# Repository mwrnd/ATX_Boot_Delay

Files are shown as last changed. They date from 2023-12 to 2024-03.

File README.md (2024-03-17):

# ATX Boot Delay

Delaying a motherboard's BIOS/UEFI boot is a simple trick that solves issues related to the [PCIe Specification's 100ms time limit](https://pcisig.com/specifications/ecr_ecn_process?speclib=100+ms). This can be done by toggling a computer's POWER button, then pressing and holding the RESET button for a second before releasing it. Or, connect a capacitor across the reset pins of an ATX motherboard's [Front Panel Header](https://www.intel.com/content/www/us/en/support/articles/000007309/intel-nuc.html).

This board is a simple 9-Pin Front Panel Header in-line replacement for ATX motherboards that allows choosing capacitor(s) to connect accross the RESET pins to delay boot.

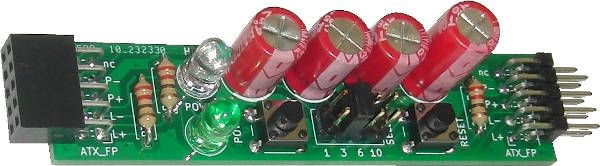
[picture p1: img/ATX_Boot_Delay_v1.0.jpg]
ATX Boot Delay Board


To use the RESET button on the board, hold it long enough to overcome the capacitor discharge delay which can be a couple of seconds.

## Usage Example

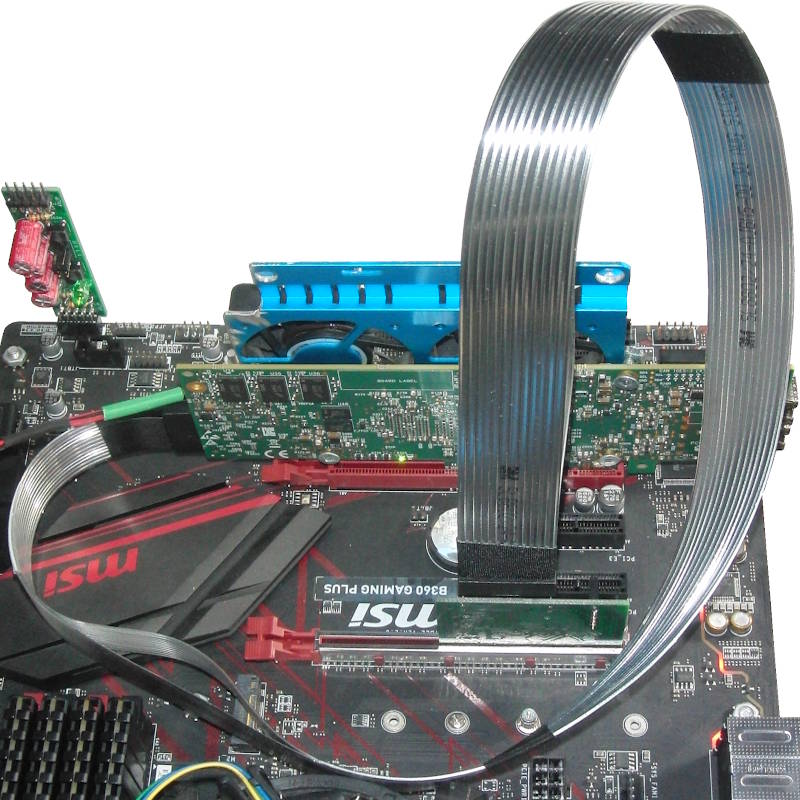
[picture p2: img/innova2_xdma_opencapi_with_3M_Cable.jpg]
ATX Boot Delay Board in a System


Close-up:

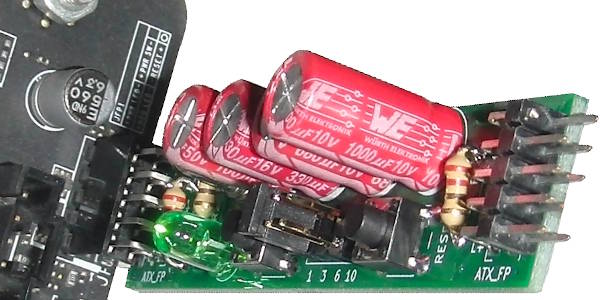
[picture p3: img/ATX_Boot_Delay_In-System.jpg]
ATX Boot Delay Board in a System Closeup


## PCB Layout

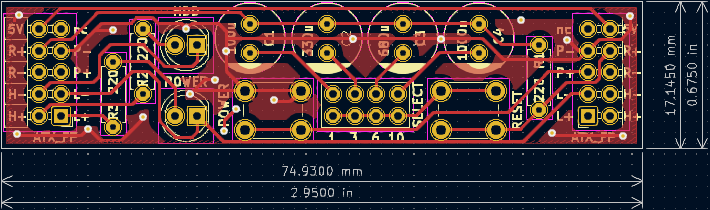
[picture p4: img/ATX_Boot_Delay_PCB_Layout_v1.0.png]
ATX Boot Delay Board PCB Layout


## Schematic

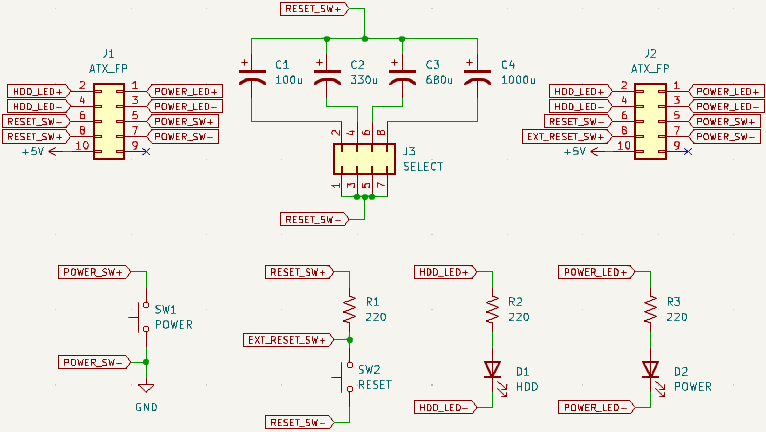
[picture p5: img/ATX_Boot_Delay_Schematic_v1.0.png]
ATX Boot Delay Board Schematic


## Bill Of Materials

| Designator(s) | Part Number | Quantity | Value | Footprint | Availability |
| --- | --- | --- | --- | --- | --- |
| C1 | 860010674014 | 1 | 100uF | C_Radial_D8.0mm_H11.5mm_P3.50mm | [DigiKey](https://www.digikey.com/en/products/detail/w%C3%BCrth-elektronik/860010674014/5726913) |
| C2 | 860010374011 | 1 | 330uF | C_Radial_D8.0mm_H11.5mm_P3.50mm | [DigiKey](https://www.digikey.com/en/products/detail/w%C3%BCrth-elektronik/860010374011/5726852) |
| C3 | 860020274013 | 1 | 680uF | C_Radial_D8.0mm_H11.5mm_P3.50mm | [DigiKey](https://www.digikey.com/en/products/detail/w%C3%BCrth-elektronik/860020274013/5727150) |
| C4 | 860010274015 | 1 | 1000uF  | C_Radial_D8.0mm_H11.5mm_P3.50mm | [DigiKey](https://www.digikey.com/en/products/detail/w%C3%BCrth-elektronik/860010274015/5726956) |
| SW1, SW2 | TS02-66-60-BK-100-LCR-D | 2 | N/A | SW_PUSH_6mm | [DigiKey](https://www.digikey.com/en/products/detail/cui-devices/TS02-66-60-BK-100-LCR-D/15634327) |
| J1 | PREC005DBAN-M71RC | 1 | N/A | PinSocket_2x05_P2.54mm_Horizontal | [DigiKey](https://www.digikey.com/en/products/detail/sullins-connector-solutions/PREC005DBAN-M71RC/2775649) |
| J2 | PPTC052LJBN-RC | 1 | N/A | PinHeader_2x05_P2.54mm_Horizontal | [DigiKey](https://www.digikey.com/en/products/detail/sullins-connector-solutions/PPTC052LJBN-RC/775977) |
| J3 | 9-146257-0-04 | 1 | N/A | PinHeader_2x04_P2.54mm_Vertical | [DigiKey](https://www.digikey.com/en/products/detail/te-connectivity-amp-connectors/9-146257-0-04/1165365)  |
| D1 | C503B-RAN-CZ0C0AA2 | 1 | RED | LED_D5.0mm | [DigiKey](https://www.digikey.com/en/products/detail/creeled-inc/C503B-RAN-CZ0C0AA2/6561762) |
| D2 | LTL-4234 | 1 | GREEN | LED_D5.0mm | [DigiKey](https://www.digikey.com/en/products/detail/liteon/LTL-4234/200373) |
| R1, R2, R3 | CF14JT220R | 1 | 220-Ohm | R_Axial_DIN0207_L6.3mm_D2.5mm | [DigiKey](https://www.digikey.com/en/products/detail/stackpole-electronics-inc/CF14JT220R/1741346) |
| Jumpers | QPC02SXGN-RC | 4 | N/A | N/A | [DigiKey](https://www.digikey.com/en/products/detail/sullins-connector-solutions/QPC02SXGN-RC/2618262) |

## Theory of Operation

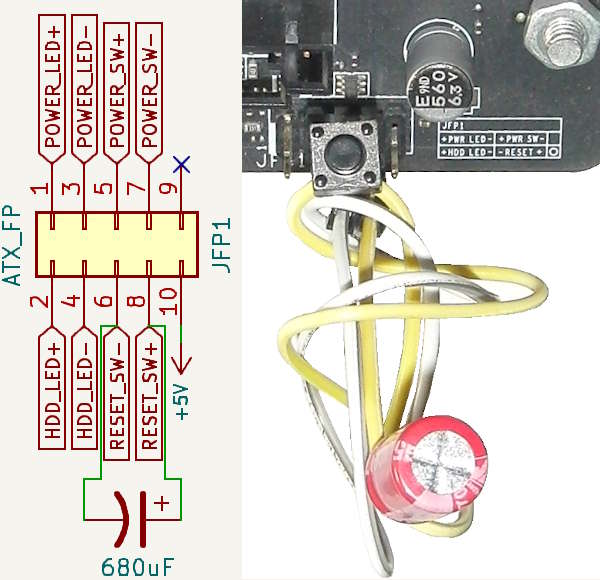
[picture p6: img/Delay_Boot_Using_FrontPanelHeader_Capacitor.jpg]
Delay Motherboard Boot Using RESET Capacitor


The capacitor across RESET works thanks to an [RC Delay](https://en.wikipedia.org/wiki/RC_time_constant) on the reset signal buffer. The [OpenCompute](https://en.wikipedia.org/wiki/Open_Compute_Project) project has a public schematic and the RESET Button is on Pg#151 in *Project_Olympus_Intel_XSP_Schematics_20171016.pdf* found in [`Project_Olympus_Intel_XSP_Collateral.zip`](http://files.opencompute.org/oc/public.php?service=files&t=e969672c57d6e17647adea54f2c3e5a7&download).

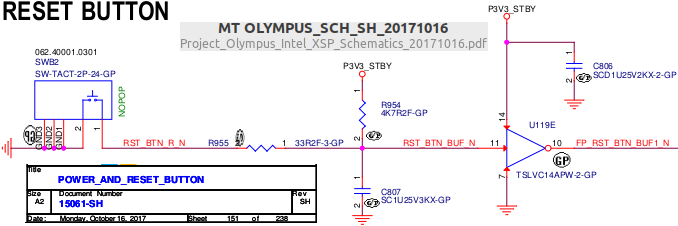
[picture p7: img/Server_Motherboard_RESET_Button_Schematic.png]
RESET Button Schematic


A standard Schmitt-Trigger inverter such as the [SN74LVC1G14](https://www.ti.com/lit/gpn/SN74LVC1G14) has a positive-going threshold voltage of about 1.5V with a 3.3V supply. I have measured 1k-Ohm between the RESET+ pin and the 3.3V ATX Power supply rail. A 330uF capacitor therefore delays boot by about 200ms. [RC Calculator](http://ladyada.net/library/rccalc.html):

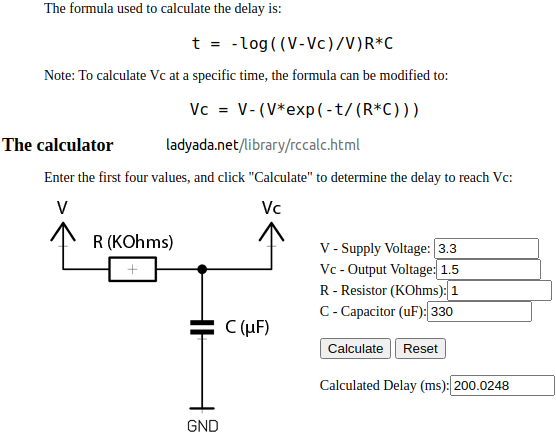
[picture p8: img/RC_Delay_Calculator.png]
RC Delay Calculator


I found out about this technique [here](https://hackaday.com/2018/02/17/catching-the-pcie-bus/):

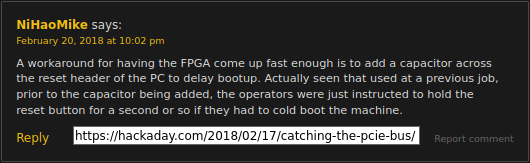
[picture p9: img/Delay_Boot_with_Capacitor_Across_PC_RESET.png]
Boot Delay Technique Source


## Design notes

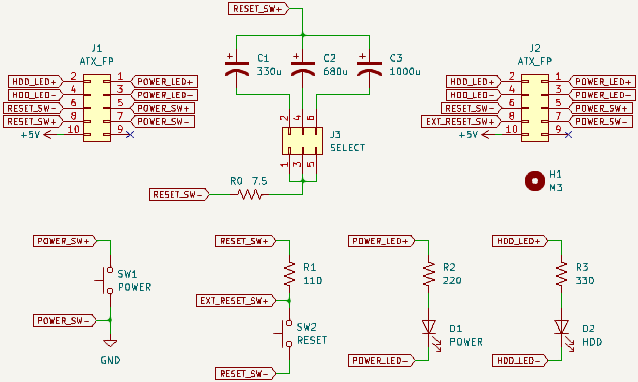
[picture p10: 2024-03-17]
img/ATX_Boot_Delay_Schematic_v1.1.png

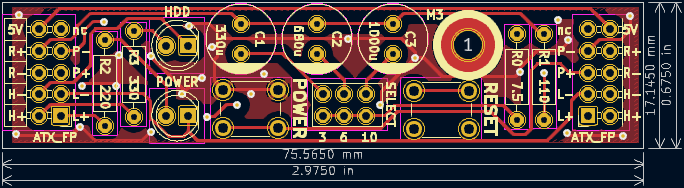
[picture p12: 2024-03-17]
img/ATX_Boot_Delay_PCB_Layout_v1.1.png

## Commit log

2023-12-14 First PCB Revision
    [ATX_Boot_Delay.kicad_pcb, ATX_Boot_Delay.kicad_sch]
2023-12-14 Update README with Bill of Materials
2024-03-17 Second Revision - v1.1
    [ATX_Boot_Delay.kicad_pcb, ATX_Boot_Delay.kicad_sch]
